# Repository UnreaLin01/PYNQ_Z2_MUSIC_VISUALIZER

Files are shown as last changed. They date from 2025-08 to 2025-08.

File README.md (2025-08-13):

# PYNQ-Z2 Music Visualizer 🎵💡



Demo Video (https://www.youtube.com/watch?v=f9keKouVoJM)

An FPGA-based real-time audio spectrum visualizer built on the PYNQ-Z2 development board. The system utilizes programmable logic (PL) for FFT acceleration and WS2812B addressable RGB LED driving, while the processor system (PS) handles audio streaming over Ethernet and generates dynamic LED panel patterns.

## ✨ Features

- Learn Zynq-7000 FPGA development through a hands-on project
- Fully leverage the strengths of both the PL and PS for optimal performance
- Deliver eye-catching, vivid, and smooth audio-reactive visuals
- Stream audio in real time over Ethernet with minimal latency
- Hardware-accelerated FFT with integrated magnitude calculation

## 📌 System Diagram



## 📽️ Demo Video
* [PYNQ-Z2 Music Visualizer - YOASOBI「Watch Me!」](https://youtu.be/f9keKouVoJM)
* [PYNQ-Z2 Music Visualizer - VALORANT x Madge「2WORLDS」](https://youtu.be/hBvHBqEr2Rw)
* [PYNQ-Z2 Music Visualizer - cute girls doing cute things「Surprise」](https://youtu.be/C2-kPhmhrjE)
* [PYNQ-Z2 Music Visualizer - Frequency Sweep 20Hz - 20KHz](https://youtu.be/82kyBqZx_8Q)

## 🛠️ Minimum Requirements

### Hardware

* PYNQ-Z2 — **1 pc**
* Micro SD Card — **1 pc**
* Micro USB Cable — **1 pc**
* Ethernet Cable — **1 pc**
* WS2812B Addressable RGB LED Strip (144 LEDs / meter) — **2 meters**
* TXS0108E Level Shifter Module — **1 pc**
* Hook-Up Wire — **some**

### Software

* BalenaEtcher
* MobaXterm
* Python
* Virtual Cable

## 📄 Full Documentation & Tutorial

* [HackMD](https://hackmd.io/@UnreaLin/H11WDXEfee)
* [Hackster](https://www.hackster.io/unrealin/pynq-z2-music-visualizer-b1bf5d)

## 📎References

* [PYNQ Official Document](https://pynq.readthedocs.io/en/latest/)
* [PYNQ Controlled NeoPixel LED Cube](https://www.hackster.io/adam-taylor/pynq-controlled-neopixel-led-cube-92a1c1)
* [FFT IP Core Tutorial Part 1: Vivado Simulation with Complex Numbers](https://www.youtube.com/watch?v=ZdCnJutIMp8)
* [FFT IP Core Tutorial Part 2: FPGA FFT Acceleration using AXI DMA](https://www.youtube.com/watch?v=HR4h_T4HZB0)

## 🙏 Acknowledgements

- [Adam Taylor](https://www.hackster.io/adam-taylor) — Original NeoPixel IP design
- [FPGAPS](https://www.youtube.com/@FPGAPS) — Excellent FFT IP tutorials

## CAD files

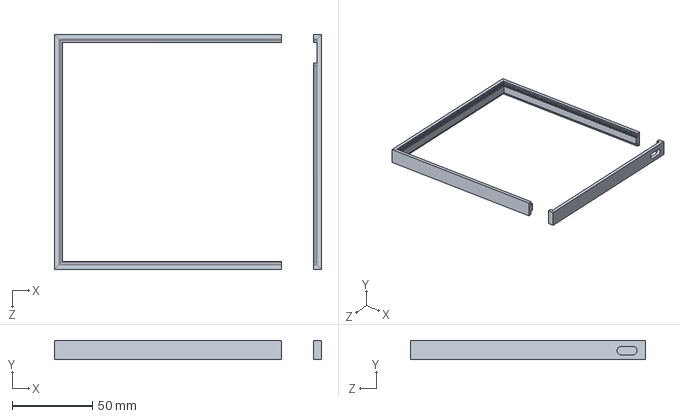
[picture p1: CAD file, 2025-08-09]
3D Model/MidFrame.SLDPRT
166.0 x 12.0 x 146.0 mm

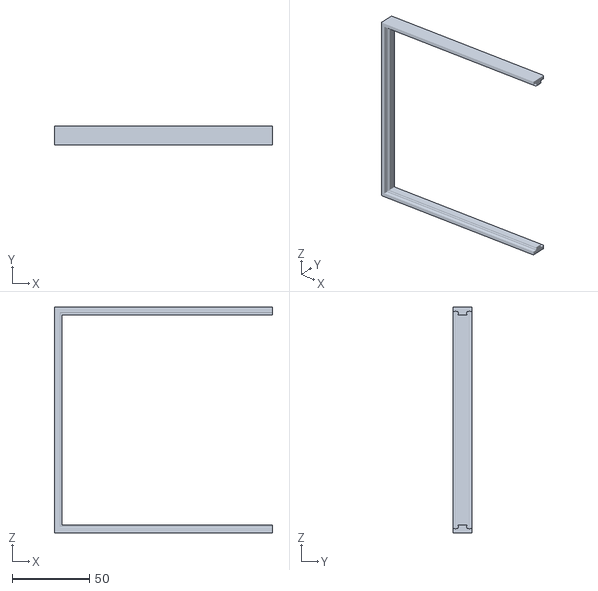
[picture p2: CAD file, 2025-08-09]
3D Model/MidFrame_Bottom.STL
141.0 x 12.0 x 146.0

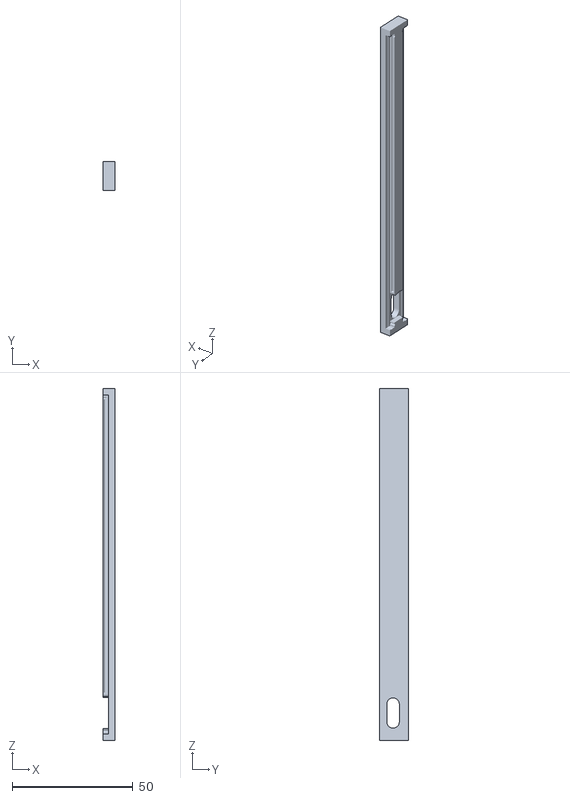
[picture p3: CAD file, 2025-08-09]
3D Model/MidFrame_Top.STL
5.00 x 12.0 x 146.0

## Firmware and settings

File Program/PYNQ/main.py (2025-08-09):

# -*- coding: utf-8 -*-
# SPDX-License-Identifier: GPL-3.0-or-later
# File: main.py
# Author: William Lin
# Copyright (C) 2025 William Lin
#
# This file is part of a project that is licensed under the terms of the
# GNU General Public License v3.0 or later. You should have received a copy
# of the license with this file. If not, see <https://www.gnu.org/licenses/>.

from pynq import Overlay, allocate, MMIO, PL
from pynq.lib import AxiGPIO
from collections import deque
import time
import matplotlib.pyplot as plt
import numpy as np
import math
import socket

UDP_PORT = 5005

MIN_DB = 15
MAX_DB = 65

SAMPLERATE = 48000
WINDOW_SIZE = 960*2
HOP_SIZE = 960


FREQ_RANGES = [
    (   2,    4), # 20   ~ 50    Hz
    (   5,    8), # 50   ~ 100   Hz
    (   9,   17), # 100  ~ 200   Hz
    (  18,   34), # 200  ~ 400   Hz
    (  35,   68), # 400  ~ 800   Hz
    (  69,  102), # 800  ~ 1200  Hz
    ( 103,  136), # 1200 ~ 1600  Hz
    ( 137,  205), # 1600 ~ 2400  Hz
    ( 206,  410), # 2400 ~ 4800  Hz
    ( 411,  819), # 4800 ~ 9600  Hz
    ( 820, 1468)  # 9600 ~ 17200 Hz
]

# Connector at bottom left
#LED_MATRIX_MAP = [
#    [  0,   1,   2,   3,   4,   5,   6,   7,   8,   9,  10,  11,  12,  13,  14,  15,  16,  17,  18],
#    [ 37,  36,  35,  34,  33,  32,  31,  30,  29,  28,  27,  26,  25,  24,  23,  22,  21,  20,  19],
#    [ 38,  39,  40,  41,  42,  43,  44,  45,  46,  47,  48,  49,  50,  51,  52,  53,  54,  55,  56],
#    [ 75,  74,  73,  72,  71,  70,  69,  68,  67,  66,  65,  64,  63,  62,  61,  60,  59,  58,  57],
#    [ 76,  77,  78,  79,  80,  81,  82,  83,  84,  85,  86,  87,  88,  89,  90,  91,  92,  93,  94],
#    [113, 112, 111, 110, 109, 108, 107, 106, 105, 104, 103, 102, 101, 100,  99,  98,  97,  96,  95],
#    [114, 115, 116, 117, 118, 119, 120, 121, 122, 123, 124, 125, 126, 127, 128, 129, 130, 131, 132],
#    [151, 150, 149, 148, 147, 146, 145, 144, 143, 142, 141, 140, 139, 138, 137, 136, 135, 134, 133],
#    [152, 153, 154, 155, 156, 157, 158, 159, 160, 161, 162, 163, 164, 165, 166, 167, 168, 169, 170],
#    [189, 188, 187, 186, 185, 184, 183, 182, 181, 180, 179, 178, 177, 176, 175, 174, 173, 172, 171],
#    [190, 191, 192, 193, 194, 195, 196, 197, 198, 199, 200, 201, 202, 203, 204, 205, 206, 207, 208],
#]

# Connector at bottom right
LED_MATRIX_MAP = [
    [190, 189, 152, 151, 114, 113,  76,  75,  38,  37,   0],
    [191, 188, 153, 150, 115, 112,  77,  74,  39,  36,   1],
    [192, 187, 154, 149, 116, 111,  78,  73,  40,  35,   2],
    [193, 186, 155, 148, 117, 110,  79,  72,  41,  34,   3],
    [194, 185, 156, 147, 118, 109,  80,  71,  42,  33,   4],
    [195, 184, 157, 146, 119, 108,  81,  70,  43,  32,   5],
    [196, 183, 158, 145, 120, 107,  82,  69,  44,  31,   6],
    [197, 182, 159, 144, 121, 106,  83,  68,  45,  30,   7],
    [198, 181, 160, 143, 122, 105,  84,  67,  46,  29,   8],
    [199, 180, 161, 142, 123, 104,  85,  66,  47,  28,   9],
    [200, 179, 162, 141, 124, 103,  86,  65,  48,  27,  10],
    [201, 178, 163, 140, 125, 102,  87,  64,  49,  26,  11],
    [202, 177, 164, 139, 126, 101,  88,  63,  50,  25,  12],
    [203, 176, 165, 138, 127, 100,  89,  62,  51,  24,  13],
    [204, 175, 166, 137, 128,  99,  90,  61,  52,  23,  14],
    [205, 174, 167, 136, 129,  98,  91,  60,  53,  22,  15],
    [206, 173, 168, 135, 130,  97,  92,  59,  54,  21,  16],
    [207, 172, 169, 134, 131,  96,  93,  58,  55,  20,  17],
    [208, 171, 170, 133, 132,  95,  94,  57,  56,  19,  18]
]

# Rainbow LUT
#RAINBOW_LUT = [
# (12,  0,  0),
# (12,  2,  0),
# (12,  4,  0),
# (12,  6,  0),
# (11,  8,  0),
# (10, 10,  0),
# ( 9, 11,  0),
# ( 7, 12,  0),
# ( 5, 12,  1),
# ( 3, 12,  3),
# ( 1, 12,  6),
# ( 0, 11,  9),
# ( 0,  9, 11),
# ( 0,  6, 12),
# ( 1,  3, 12),
# ( 3,  1, 12),
# ( 6,  0, 11),
# ( 9,  0,  7),
# (12, 12, 12)
#]

RAINBOW_LUT = [
 ( 6, 0, 0),
 ( 6, 1, 0),
 ( 6, 2, 0),
 ( 6, 3, 0),
 ( 5, 4, 0),
 ( 5, 5, 0),
 ( 4, 5, 0),
 ( 3, 6, 0),
 ( 2, 6, 1),
 ( 1, 6, 3),
 ( 0, 6, 3),
 ( 0, 5, 4),
 ( 0, 4, 5),
 ( 0, 3, 6),
 ( 1, 2, 6),
 ( 1, 1, 6),
 ( 3, 0, 6),
 ( 4, 0, 3),
 ( 5, 5, 5)
]

class FFTAccelerator:
    def __init__(self, overlay):
    
        # Retrieve IP information from .hwh file
        self.dma = overlay.axi_dma_0
        
        # Allocate a space in DDR memory for DMA transmit and receive.
        self.dma_tx_buffer = allocate(shape=(4096,), dtype=np.uint32)
        self.dma_rx_buffer = allocate(shape=(4096,), dtype=np.float32)
    
    def execute(self, samples):
        self.dma_tx_buffer[:len(samples)] = samples
        self.dma.recvchannel.transfer(self.dma_rx_buffer)
        self.dma.sendchannel.transfer(self.dma_tx_buffer)
        self.dma.sendchannel.wait()
        self.dma.recvchannel.wait()
        return self.dma_rx_buffer


#class NeoPixel:
#    def __init__(self, base_addr = 0x80000000, mem_size = 1024, num_leds = 1):
#        self.mmio = MMIO(base_addr, mem_size)
#        self.num_leds = max(min(num_leds, 1023), 0)
#        self.base_addr = base_addr
#        self.addr_step = 0x4
#        self.mmio.write(0x0, self.num_leds)
#    
#    def get_led_num(self):
#        return self.num_leds
#        
#    def set_rgb(self, index, r, g, b):
#        if 0 <= index < self.num_leds:
#            r = max(min(r, 255), 0)
#            g = max(min(g, 255), 0)
#            b = max(min(b, 255), 0)
#            color = g << 16 | r << 8 | b
#            self.mmio.write(0x4 + (0x4 * index), color)
#            
#    def set_rgb_all(self, r, g, b):
#        for i in range(self.num_leds):
#            self.set_rgb(i, r, g, b)
#            
#    def close(self):
#        for i in range(self.num_leds):
#            self.set_rgb(i, 0, 0, 0)


class NeoPixel:
    def __init__(self, base_addr=0x80000000, mem_size=1024, num_leds=1):
        self.mmio = MMIO(base_addr, mem_size)
        self.num_leds = max(min(num_leds, 1023), 0)
        self.base_addr = base_addr
        self.addr_step = 0x4
        self.led_state = [(0, 0, 0)] * self.num_leds
        self.mmio.write(0x0, self.num_leds)

    def get_led_num(self):
        return self.num_leds

    def set_rgb(self, index, r, g, b):
        current = self.led_state[index]
        if current != (r, g, b):
            self.led_state[index] = (r, g, b)
            color = g << 16 | r << 8 | b
            self.mmio.write(0x4 + self.addr_step * index, color)

    def set_rgb_all(self, r, g, b):
        for i in range(self.num_leds):
            self.set_rgb(i, r, g, b)

    def close(self):
        self.set_rgb_all(0, 0, 0)

            
class IO:
    def __init__(self, overlay):
    
        # Retrieve IP information from .hwh file
        self.leds = overlay.leds.channel1
        self.btns = overlay.btns.channel1
        self.sws = overlay.sws.channel1
        
    def set_led(self, index, state):
        if index <= 3 and index >= 0:
            if state == 1 or state == 0:
                self.leds.write(state << index, 0b0001 << index)
                
    def set_led_all(self, state):
        if state == 1:
            self.leds.write(0b1111, 0b1111)
        elif state == 0:
            self.leds.write(0b0000, 0b1111)
            
    def get_btn_state(self, index):
        if index <= 3 and index >= 0:
            return (self.btns.read() >> index) & 0b0001
        return -1
        
    def get_sw_state(self, index):
        if index <= 1 and index >= 0:
            return (self.sws.read() >> index) & 0b0001
        return -1

def main():

    # Clear cache
    PL.reset()
    
    # Load bitstream file into SRAM
    print("Loading Bitstream...")
    overlay = Overlay("design_1_wrapper.bit", download=True)
    print("Bitstream Loaded!")

    # Initialize IPs
    fft = FFTAccelerator(overlay)
    io = IO(overlay)
    
    # Initialize and test LED panel
    ws2812 = NeoPixel(num_leds = 209)
    ws2812.set_rgb_all(10, 0, 0)
    time.sleep(0.5)
    ws2812.set_rgb_all(0, 10, 0)
    time.sleep(0.5)
    ws2812.set_rgb_all(0, 0, 10)
    time.sleep(0.5)
    ws2812.close()
    
#    for i in range(ws2812.get_led_num()):
#        ws2812.set_rgb(i, 5, 5, 5)
#        time.sleep(0.01)
#        
#    for i in range(ws2812.get_led_num()):
#        ws2812.set_rgb(i, 0, 0, 0)
#        time.sleep(0.01)
        
    for x in range(11):
        for y in range(19):
            ws2812.set_rgb(LED_MATRIX_MAP[y][x], 5, 5, 5)
            time.sleep(0.005)
            
    for x in range(11):
        for y in range(19):
            ws2812.set_rgb(LED_MATRIX_MAP[y][x], 0, 0, 0)
            time.sleep(0.005)
    
    
    # Initialize UDP server
    print("Initial UDP Server...")
    sock = socket.socket(socket.AF_INET, socket.SOCK_DGRAM)
    sock.bind(("0.0.0.0", UDP_PORT))
    print(f'Listening on Port {UDP_PORT}...')
    
    loop_count = 0
    start_time = time.time()
    
    alpha = 0.4  
    levels = np.zeros(11, dtype = np.float32)
    levels_smoothed = np.zeros(11, dtype = np.float32)
    normalization = np.zeros(11, dtype = np.float32)    
    
    audio_buffer = deque(maxlen = WINDOW_SIZE)
    window_function = np.hanning(WINDOW_SIZE)
    
    while True:
        data, addr = sock.recvfrom(8192)
        audio_samples = np.frombuffer(data, dtype=np.int16)
        
        audio_buffer.extend(audio_samples)
        if len(audio_buffer) == WINDOW_SIZE:
            fft_result = fft.execute((np.array(audio_buffer) * window_function).astype(np.int16))
            audio_buffer = deque(list(audio_buffer)[HOP_SIZE:], maxlen = WINDOW_SIZE)
        
#            for i, (start, end) in enumerate(FREQ_RANGES):
#                levels[i] = 20 * np.log10(np.max(fft_result[start:end]) + 0.89125093)
#            
#            normalization = np.clip((levels - MIN_DB) / (MAX_DB - MIN_DB), 0.0, 1.0)

            for i, (start, end) in enumerate(FREQ_RANGES):
                levels[i] = 20 * np.log10(np.max(fft_result[start:end]) + 0.89125093)
            
            levels_smoothed = alpha * levels_smoothed + (1 - alpha) * levels
            normalization = np.clip((levels_smoothed - MIN_DB) / (MAX_DB - MIN_DB), 0.0, 1.0)
            
            for x in range(11):
                on_num = int(normalization[x] * 19)
                for y in range(19):
                  if on_num > y:
                    ws2812.set_rgb(LED_MATRIX_MAP[y][x], *RAINBOW_LUT[y])
                  else:
                    ws2812.set_rgb(LED_MATRIX_MAP[y][x], 0, 0, 0)
            
#            if io.get_sw_state(0) == 1:
#            print("  ".join(f"{lv:5.2f}" for lv in levels))
            
            loop_count += 1
            if time.time() - start_time >= 1.0:
                elapsed_time = time.time() - start_time
                print(f'loop count:{loop_count}, cost {elapsed_time / loop_count * 1000} ms')
                loop_count = 0
                start_time = time.time()
        
if __name__ == "__main__":
    main()

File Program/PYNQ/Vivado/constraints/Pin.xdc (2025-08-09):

set_property PACKAGE_PIN L14 [get_ports {CLK_IND[0]}]
set_property IOSTANDARD LVCMOS33 [get_ports {CLK_IND[0]}]
set_property PACKAGE_PIN W18 [get_ports RGBLED_DOUT]
set_property IOSTANDARD LVCMOS33 [get_ports RGBLED_DOUT]



set_property DRIVE 12 [get_ports {CLK_IND[0]}]
